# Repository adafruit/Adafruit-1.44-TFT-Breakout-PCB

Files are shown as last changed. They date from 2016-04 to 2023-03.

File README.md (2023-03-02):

## Adafruit 1.44" TFT LCD Color Display Breakout PCB

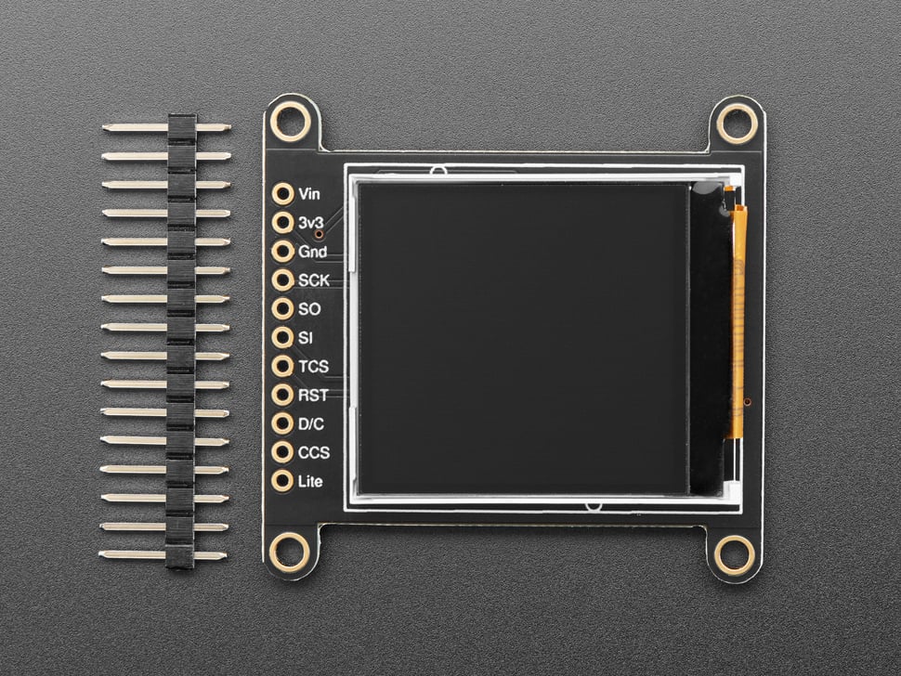
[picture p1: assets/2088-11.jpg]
<a href="http://www.adafruit.com/products/2088"><br/>
Click here to purchase one from the Adafruit shop</a>

PCB files for the Adafruit 1.44 TFT Breakout. Format is EagleCAD schematic and board layout
* https://www.adafruit.com/products/2088

### Description

This lovely little display breakout is the best way to add a small, colorful and bright display to any project. Since the display uses 4-wire SPI to communicate and has its own pixel-addressable frame buffer, it can be used with every kind of microcontroller. Even a very small one with low memory and few pins available!

The 1.44" display has 128x128 color pixels. Unlike the low cost "Nokia 6110" and similar LCD displays, which are CSTN type and thus have poor color and slow refresh, this display is a true TFT! The TFT driver (ST7735R) can display full 16-bit color using our library code.

The breakout has the TFT display soldered on (it uses a delicate flex-circuit connector) as well as a ultra-low-dropout 3.3V regulator and a 3/5V level shifter so you can use it with 3.3V or 5V power and logic. We also had a little space so we placed a microSD card holder so you can easily load full color bitmaps from a FAT16/FAT32 formatted microSD card. The microSD card is not included.

NEW! As of February 28, 2023 - we've updated this TFT breakout with an EYESPI connector to make cabling easier with an 18-pin FPC. We also used Adafruit Pinguin to make a lovely silkscreen. The board is otherwise the same size, pinout, and functionality.

### License

Adafruit invests time and resources providing this open source design, please support Adafruit and open-source hardware by purchasing products from [Adafruit](https://www.adafruit.com)!

Designed by Limor Fried/Ladyada for Adafruit Industries.

Creative Commons Attribution/Share-Alike, all text above must be included in any redistribution. See license.txt for additional details.

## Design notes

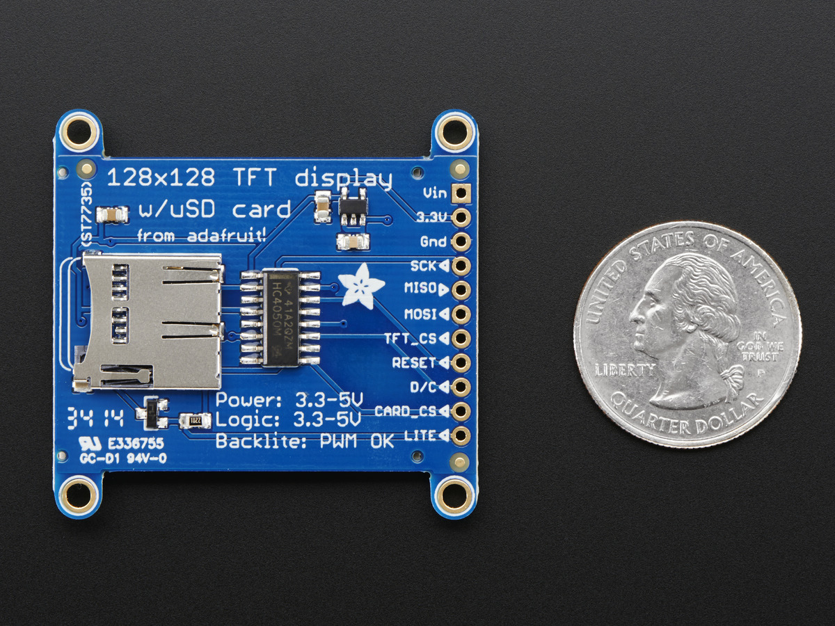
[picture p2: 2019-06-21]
assets/image.jpg

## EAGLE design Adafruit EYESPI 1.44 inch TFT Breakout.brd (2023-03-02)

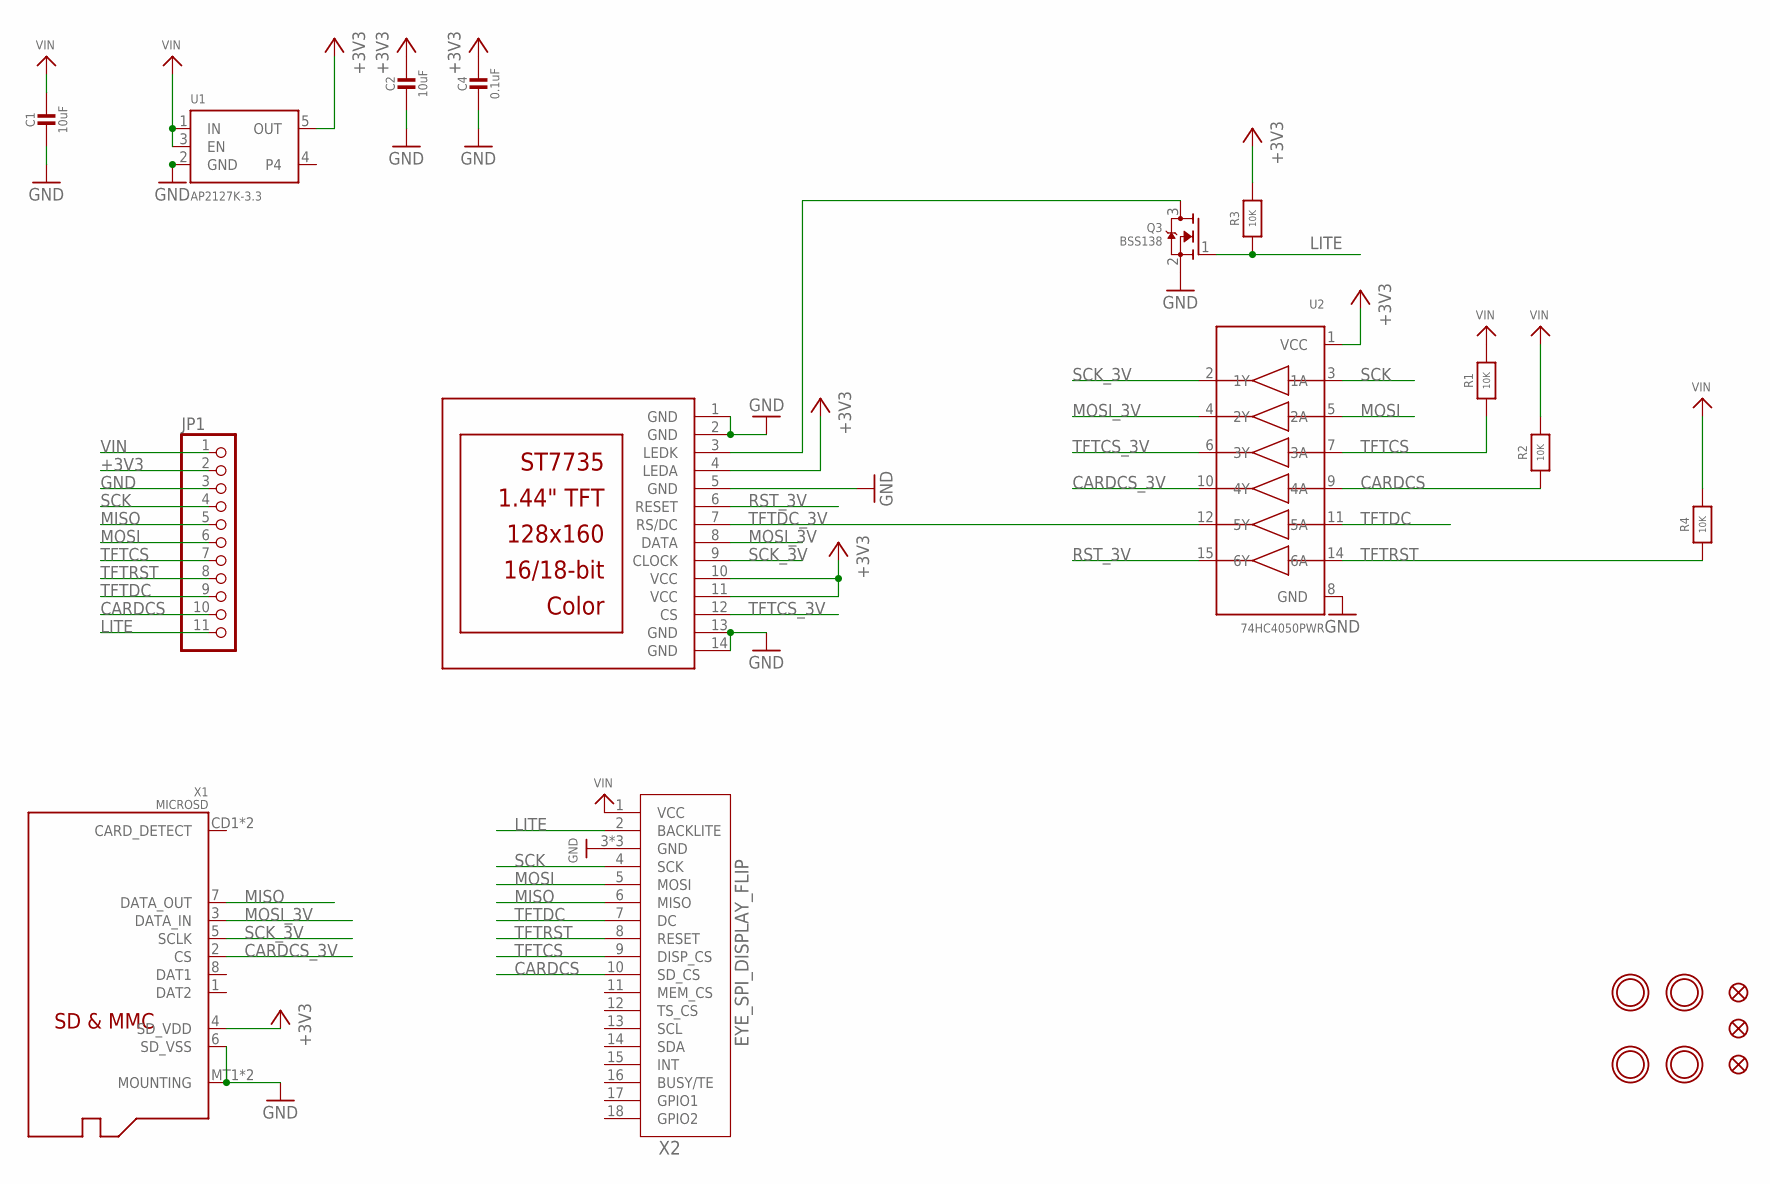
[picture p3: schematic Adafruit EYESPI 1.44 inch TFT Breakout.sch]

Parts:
C1, C2: 10uF; 0805-NO
C4: 0.1uF; 0603-NO
JP1: HEADER-1X1176MIL; 1X11_ROUND_76
Q3: BSS138; SOT23-WIDE
R1, R2, R3, R4: 10K; 0603-NO
TFT2: DISP_LCD_ST7735_1.44IN; TFT_1.44IN_128_128
U1: AP2127K-3.3; SOT23-5
U2: 74HC4050PWR; TSSOP16
U$3, U$4, U$5: FIDUCIAL_1MM
U$7, U$8, U$9, U$10: MOUNTINGHOLE2.5; MOUNTINGHOLE_2.5_PLATED
X1: MICROSD
X2: EYE_SPI_DISPLAY_FLIP; EYE_SPI_DISPLAY_BOTCONTACT

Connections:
+3V3: C2.1, C4.1, JP1.2, R3.2, TFT2.4 (LEDA), TFT2.10 (VCC), TFT2.11 (VCC), U1.5 (OUT), U2.1 (VCC), X1.4 (SD_VDD)
CARDCS: JP1.10, R2.1, U2.9 (4A), X2.10 (SD_CS)
CARDCS_3V: U2.10 (4Y), X1.2 (CS)
GND: C1.2, C2.2, C4.2, JP1.3, Q3.2 (S), TFT2.1 (GND), TFT2.2 (GND), TFT2.5 (GND), TFT2.13 (GND), TFT2.14 (GND), U1.2 (GND), U2.8 (GND), X1.6 (SD_VSS), X1.MT1 (MOUNTING), X1.MT2 (MOUNTING), X2.3 (GND), X2.SUPPORT1 (GND), X2.SUPPORT2 (GND)
LITE: JP1.11, Q3.1 (G), R3.1, X2.2 (BACKLITE)
MISO: JP1.5, X1.7 (DATA_OUT), X2.6 (MISO)
MOSI: JP1.6, U2.5 (2A), X2.5 (MOSI)
MOSI_3V: TFT2.8 (DATA), U2.4 (2Y), X1.3 (DATA_IN)
unnamed: Q3.3 (D), TFT2.3 (LEDK)
RST_3V: TFT2.6 (RESET), U2.15 (6Y)
SCK: JP1.4, U2.3 (1A), X2.4 (SCK)
SCK_3V: TFT2.9 (CLOCK), U2.2 (1Y), X1.5 (SCLK)
TFTCS: JP1.7, R1.1, U2.7 (3A), X2.9 (DISP_CS)
TFTCS_3V: TFT2.12 (CS), U2.6 (3Y)
TFTDC: JP1.9, U2.11 (5A), X2.7 (DC)
TFTDC_3V: TFT2.7 (RS/DC), U2.12 (5Y)
TFTRST: JP1.8, R4.1, U2.14 (6A), X2.8 (RESET)
VIN: C1.1, JP1.1, R1.2, R2.2, R4.2, U1.1 (IN), U1.3 (EN), X2.1 (VCC)

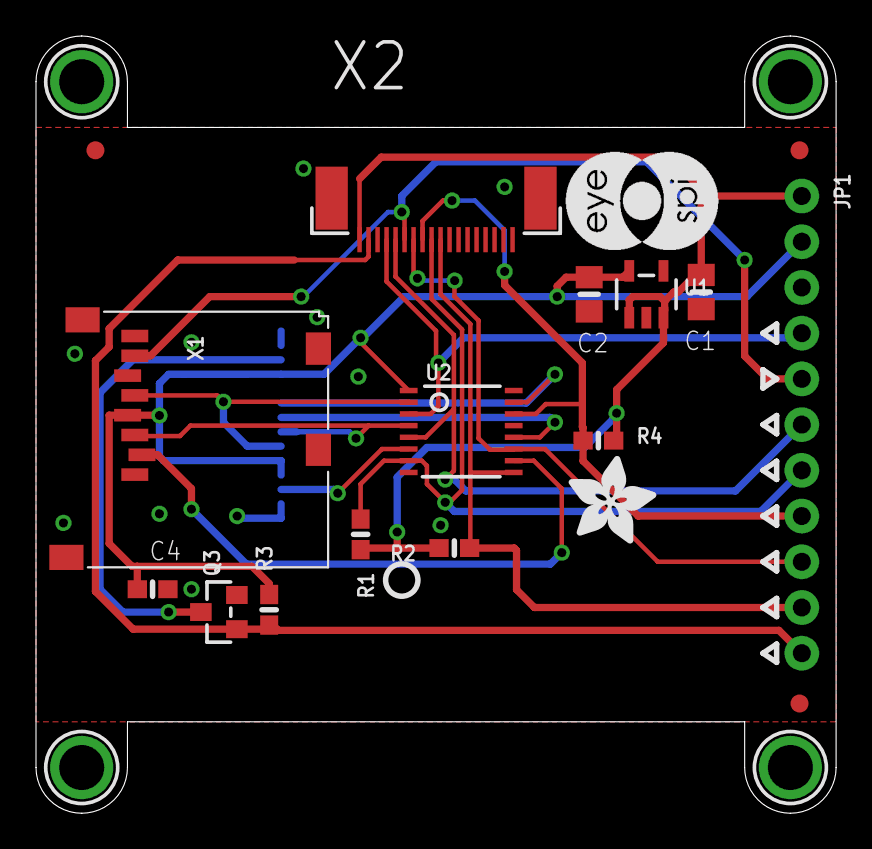
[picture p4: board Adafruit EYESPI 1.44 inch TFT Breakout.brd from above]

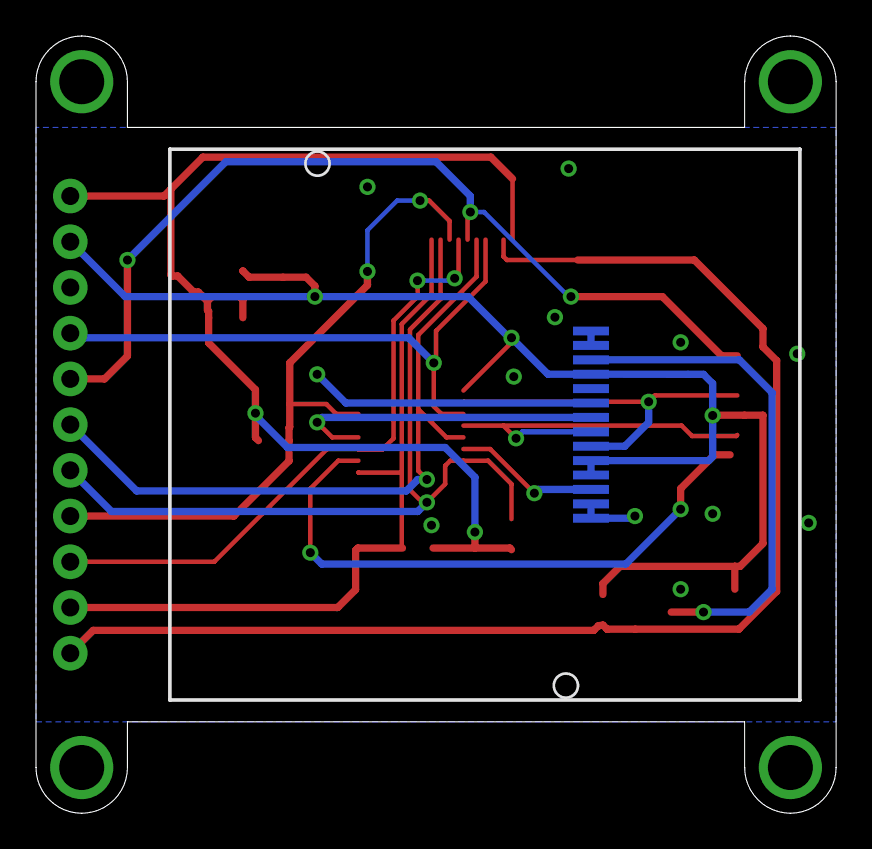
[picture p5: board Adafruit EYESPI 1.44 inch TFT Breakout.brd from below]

Board: 2 copper layers, 44.5 x 43.2 mm, 51 parts (12 on the bottom side), 18 nets.

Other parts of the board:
PLABEL0: PLABEL0
PLABEL1: PLABEL1
PLABEL2: PLABEL2
PLABEL3: PLABEL3
PLABEL4: PLABEL4
PLABEL5: PLABEL5
PLABEL6: PLABEL6
PLABEL7: PLABEL7
PLABEL8: PLABEL8
PLABEL9: PLABEL9
PLABEL10: PLABEL10
PLABEL11: PLABEL11
PLABEL12: PLABEL12
PLABEL13: PLABEL13
PLABEL14: PLABEL14
PLABEL15: PLABEL15
PLABEL16: PLABEL16
PLABEL17: PLABEL17
PLABEL18: PLABEL18
PLABEL19: PLABEL19
PLABEL20: PLABEL20
PLABEL21: PLABEL21
PLABEL22: PLABEL22
PLABEL23: PLABEL23
PLABEL24: PLABEL24
PLABEL25: PLABEL25
PLABEL26: PLABEL26
U$1: ADAFRUIT_5MM
U$2: PCBFEAT-REV-040
U$17: EYESPI_MINI_LOGO

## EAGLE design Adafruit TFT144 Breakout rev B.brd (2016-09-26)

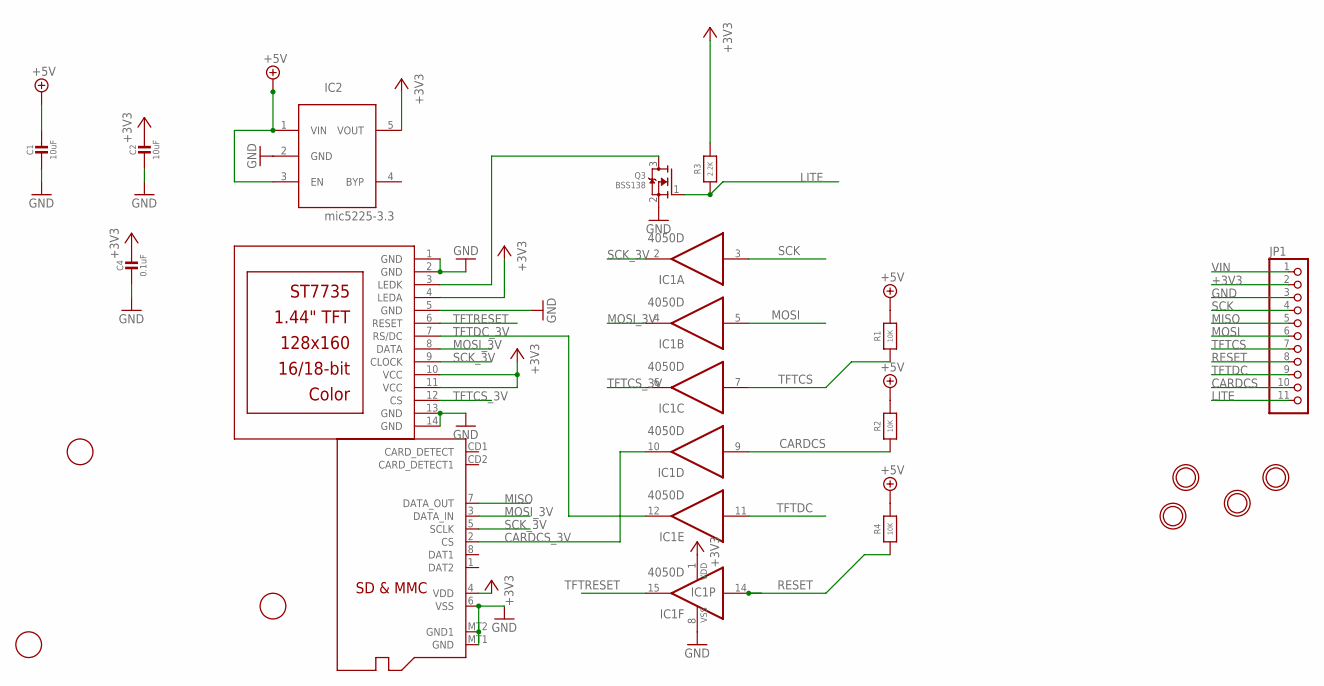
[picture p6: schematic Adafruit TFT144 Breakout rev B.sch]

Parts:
C1, C2: 10uF; 0805-NO
C4: 0.1uF; 0805-NO
IC1: 4050D; SO16
IC2: mic5225-3.3; SOT23-5L
JP1: HEADER-1X1176MIL; 1X11_ROUND_76
Q2: MICROSD
Q3: BSS138; SOT23-WIDE
R1, R2, R4: 10K; 0805-NO
R3: 2.2K; 0805-NO
TFT2: DISP_LCD_ST7735_1.44IN; TFT_1.44IN_128_128
U$3, U$4, U$5: FIDUCIAL; FIDUCIAL_1MM
U$7, U$8, U$9, U$10: MOUNTINGHOLE2.5; MOUNTINGHOLE_2.5_PLATED

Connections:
+3V3: C2.1, C4.1, IC1.1 (VDD), IC2.5 (VOUT), JP1.2, Q2.4 (VDD), R3.2, TFT2.4 (LEDA), TFT2.10 (VCC), TFT2.11 (VCC)
CARDCS: IC1.9 (I), JP1.10, R2.1
CARDCS_3V: IC1.10 (O), Q2.2 (CS)
GND: C1.2, C2.2, C4.2, IC1.8 (VSS), IC2.2 (GND), JP1.3, Q2.6 (VSS), Q2.MT1 (GND), Q2.MT2 (GND1), Q3.2 (S), TFT2.1 (GND), TFT2.2 (GND), TFT2.5 (GND), TFT2.13 (GND), TFT2.14 (GND)
LITE: JP1.11, Q3.1 (G), R3.1
MISO: JP1.5, Q2.7 (DATA_OUT)
MOSI: IC1.5 (I), JP1.6
MOSI_3V: IC1.4 (O), Q2.3 (DATA_IN), TFT2.8 (DATA)
unnamed: Q3.3 (D), TFT2.3 (LEDK)
RESET: IC1.14 (I), JP1.8, R4.1
SCK: IC1.3 (I), JP1.4
SCK_3V: IC1.2 (O), Q2.5 (SCLK), TFT2.9 (CLOCK)
TFTCS: IC1.7 (I), JP1.7, R1.1
TFTCS_3V: IC1.6 (O), TFT2.12 (CS)
TFTDC: IC1.11 (I), JP1.9
TFTDC_3V: IC1.12 (O), TFT2.7 (RS/DC)
TFTRESET: IC1.15 (O), TFT2.6 (RESET)
VIN: C1.1, IC2.1 (VIN), IC2.3 (EN), JP1.1, R1.2, R2.2, R4.2

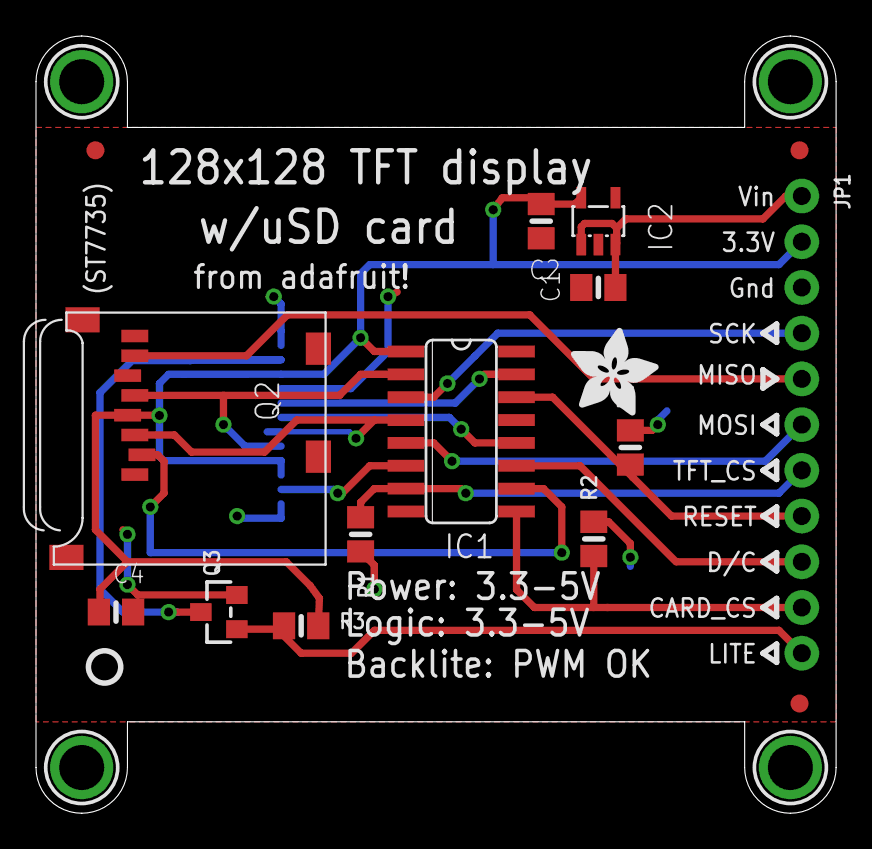
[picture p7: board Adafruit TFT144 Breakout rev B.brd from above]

Board: 2 copper layers, 44.5 x 43.2 mm, 22 parts (1 on the bottom side), 18 nets.

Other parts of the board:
U$1: ADAFRUIT_5MM
U$2: PCBFEAT-REV-040

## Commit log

2016-09-26 latest vers
    [Adafruit TFT144 Breakout rev B.brd, Adafruit TFT144 Breakout rev B.sch]
2023-03-02 adding EYESPI files and updating readme
    [Adafruit EYESPI 1.44 inch TFT Breakout.brd, Adafruit EYESPI 1.44 inch TFT Breakout.sch]

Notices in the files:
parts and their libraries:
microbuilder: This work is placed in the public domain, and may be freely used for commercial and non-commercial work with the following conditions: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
